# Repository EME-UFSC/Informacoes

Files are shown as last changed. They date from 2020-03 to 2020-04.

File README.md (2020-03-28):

<p align="center">
  <a href="https://eme-ufsc.github.io/Informacoes/">
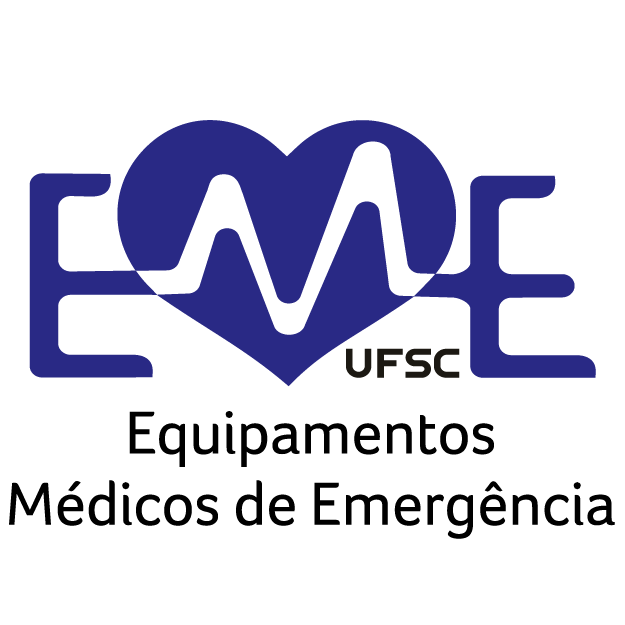
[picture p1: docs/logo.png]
Logo EME-UFSC
    
  </a>
</p>

## O que sao EMEs
Equipamentos médicos de emergencia (EMEs) sao equipamentos produzidos com o intuito de auxiliar no atendimento a emergencias médicas. Estes equipamentos nao sao certificados, porém passam por um controle no seu projeto e produçao para garantir que preencham requisitos minimos de ergonomia e higiene.

Atualmente o grupo EME-UFSC produz os seguintes equipamentos:
- Escudo facial
- Mascara de boca/nariz
- Avental
- Ventilador mecanico

## Quer ajudar ou precisa de ajuda?
Primeiramente precisamos saber onde voce precisa de ajuda ou como pode ajudar. Para isso, pedimos que preencha um dos formularios abaixo. **Demora menos de um minuto** e nos ajuda a gerenciar nossa demanda e capacidade de produçao. Em seguida [acesse nosso Slack](https://join.slack.com/t/eme-ufsc/shared_invite/zt-d20z4zog-~3Gnwx_5Q57T4ACO6nKYkg) e entre no canal mais adequado.

- #### Pode ajudar financeiramente? [**Clique aqui.**](docs/ajuda_financeira.md)

- #### Precisa de equipamento para sua Unidade de Saude? Preencha [este formulario](https://docs.google.com/forms/d/e/1FAIpQLSfDX15ljiZy6SYf0Oby2XscRVzy2pqgRojPx5fv6pEW_O75Uw/viewform).

- #### Possui maquinario para ajudar na produçao? Preencha [este formulario](https://forms.gle/Hm4whJZQ5EAF3oUG9).

- #### Possui algum dos [insumos aqui listados](docs/insumos.md) para doar ou vender? Preencha [este formulario](https://forms.gle/EKddxEwn4KSwLAXHA).

- #### Possui alguma duvida quanto ao projeto EME-UFSC? Preencha [este formulario](https://forms.gle/3jeLeoqR6PNNrrAi8).

- #### Aonde devo entregar os equipamentos? [Acesse aqui](docs/entrega.md).

## Outros links

- #### [Grupos de trabalho](docs/grupos_de_trabalho.md)
- #### [Projetos externos de EME](docs/projetos_externos_de_eme.md)
- #### [Arquivos para manufatura](docs/arquivos_de_manufatura.md)
- #### [Noticias](docs/noticias.md)
- #### [Resolução de fabricação e aquisição de dispositivos médicos em virtude da emergência de saúde pública](http://www.in.gov.br/en/web/dou/-/resolucao-rdc-n-356-de-23-de-marco-de-2020-249317437)

## Fotos da comunidade

- #### [Acervo local](docs/fotos/README.md)

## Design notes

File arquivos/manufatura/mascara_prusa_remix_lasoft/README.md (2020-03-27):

# Mascara modelo Prusa Remix Lasoft
Mascara de produção rapida e confortavel 

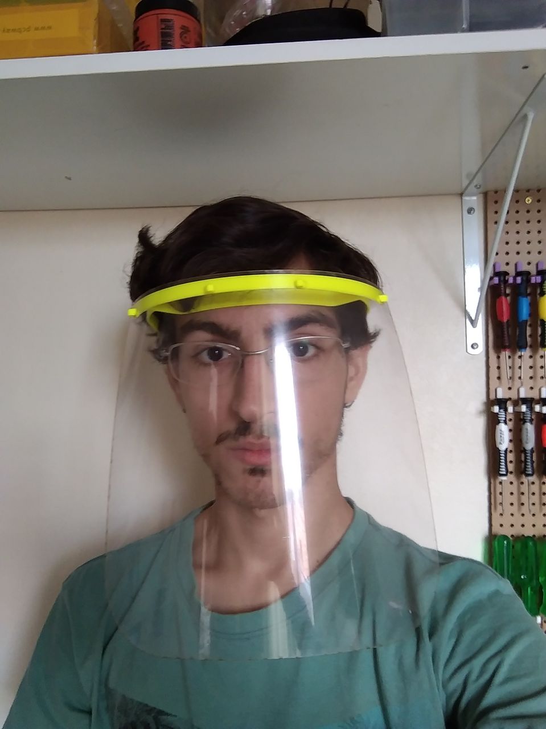
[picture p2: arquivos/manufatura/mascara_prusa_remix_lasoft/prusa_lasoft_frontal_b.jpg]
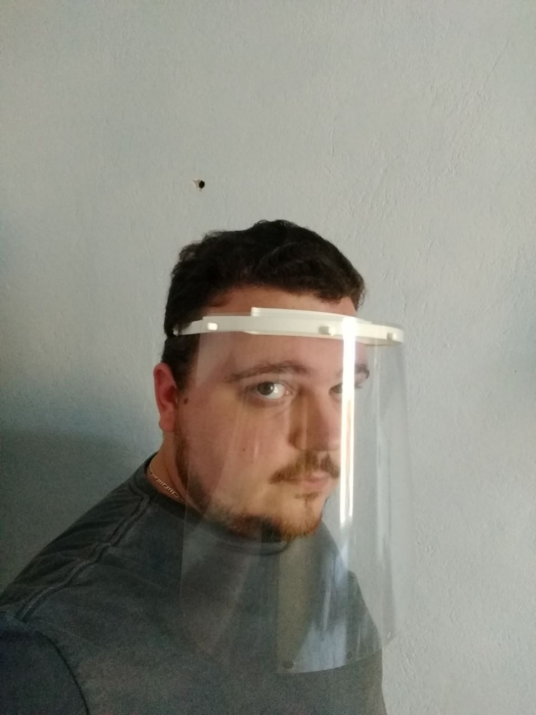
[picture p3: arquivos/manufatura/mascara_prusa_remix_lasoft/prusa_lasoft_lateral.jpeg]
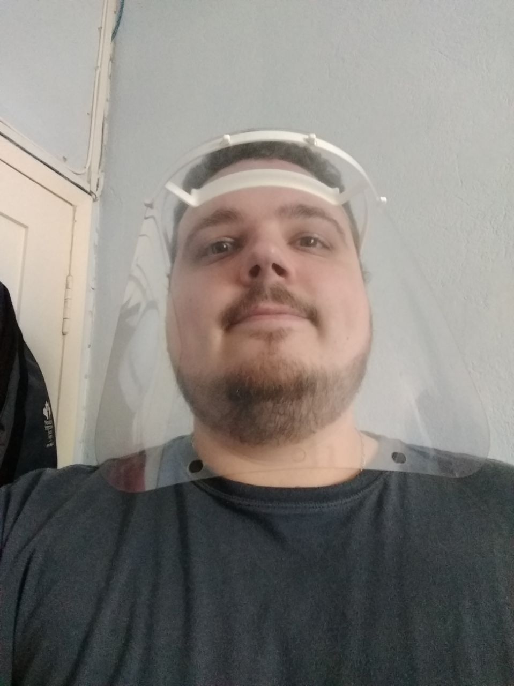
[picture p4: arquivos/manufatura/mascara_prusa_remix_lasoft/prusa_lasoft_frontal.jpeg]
  

## Arquivos
- [Suporte superior (.stl)](single-face-shield-lasoft-modified.stl)

## Vantagens
- Impressao rapida (1:30h)
- Pouco material (10g de filamento)

## Desvantagens
- Encaixe do acetato é quadrado

## BOM
- Suporte superior (impresso)
- Folha de acetato 24x24cm (0.5mm de espessura)
- Elastico

## Instruçoes para confecçao

- Imprimir os suportes
- Encaixar a folha de acetato
- Prender o elastico

## Configuraçao de impressao
- Numero de perimetros: 3;
- Percentual de infill: 20%;
- Altura de camada: 0.22mm;
- Velocidade planar: 60 mm/s;

## Limpeza
(?)

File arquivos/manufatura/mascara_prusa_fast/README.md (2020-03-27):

# Mascara-escudo modelo "Prusa FAST"
Modelo rapido desenvolvido pela empresa Prusa3D

## Arquivos
- [Suporte superior (.stl)](prusa_fast_superior.stl)
- [Suporte inferior (.stl)](prusa_fast_inferior.stl)
- [Desenho de corte (.dxf)](shield_final.dxf)

## Vantagens
- Ja validada por instituiçoes de saude
- Confortavel
- Firme
- Rapida
- Gasta pouco filamento

## Desvantagens
- N/A

## BOM
- Suporte superior (impresso)
- Suporte inferior (impresso)
- Folha de acetato 24x24cm (0.5mm de espessura)
- Elastico

## Instruçoes para confecçao

- Imprimir os suportes
- Encaixar a folha de acetato
- Prender o elastico

## Configuraçao de impressao
- Numero de perimetros: 3;
- Percentual de infill: 20%;
- Altura de camada: 0.22mm;
- Velocidade planar: 60 mm/s;

## Limpeza
(?)

## Referencia
https://blog.prusaprinters.org/from-design-to-mass-3d-printing-of-medical-shields-in-three-days/

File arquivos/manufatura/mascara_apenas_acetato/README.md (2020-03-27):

# Mascara modelo "Apenas Acetato"
Mascara de produção super rapida

## Arquivos
- [Instruçoes de montagem (.pdf)](Assembly_instruction.pdf)
- [Desenho de corte (.dxf)](https://eme-ufsc.github.io/Informacoes/arquivos/manufatura/mascara_apenas_acetato/shield_apenas_acetato.dxf)

## Vantagens
- Utiliza apenas acetato na estrutura, sem peças impressas
- Barata
- Rapida de produzir

## Desvantagens
- Ainda nao se conhece

## BOM
- Folha de acetato 22x30cm (0.5mm de espessura)
- Elastico

## Instruçoes para confecçao

- Cortar as peças na folha de acetato (aceita maquinas de corte a laser, corte a agua ou de laminas)
- Prender o elastico

## Limpeza
(?)

## Referencia
https://hackaday.io/project/170481-laser-cut-medical-shield

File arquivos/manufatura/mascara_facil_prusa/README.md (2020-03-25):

# Mascara-escudo modelo "Prusa RC2"
Modelo original desenvolvido pela empresa Prusa3D

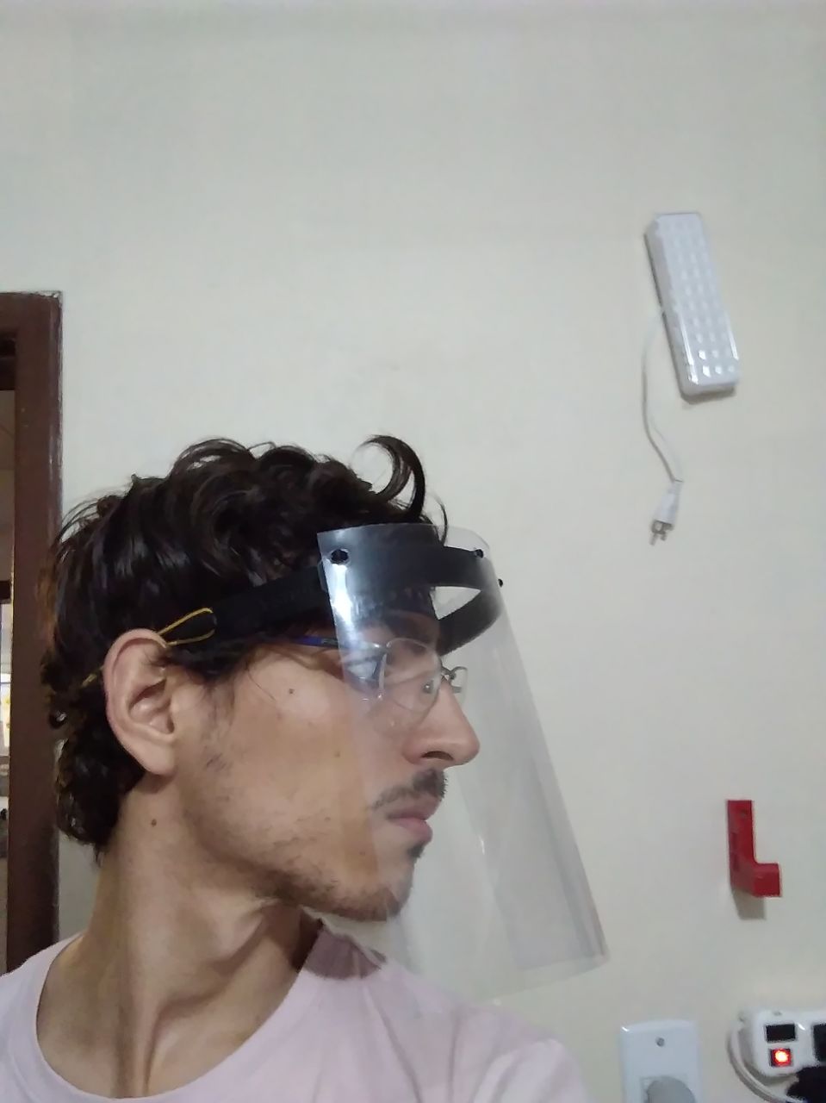
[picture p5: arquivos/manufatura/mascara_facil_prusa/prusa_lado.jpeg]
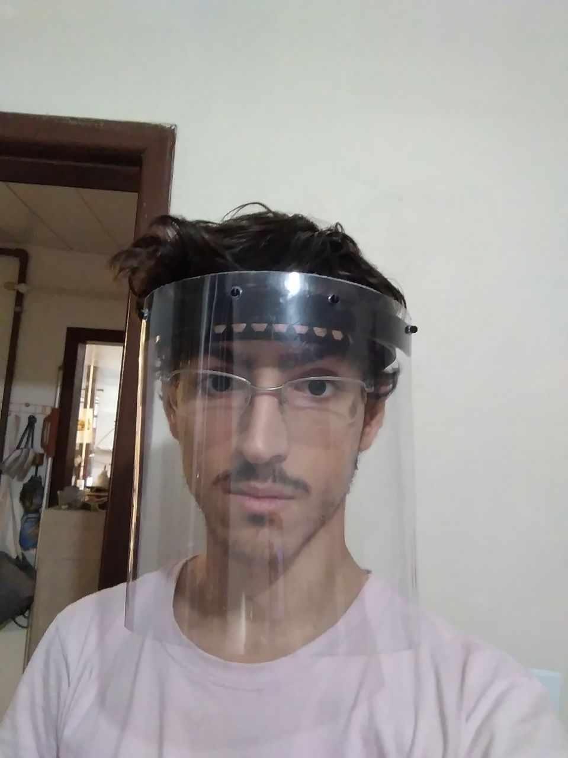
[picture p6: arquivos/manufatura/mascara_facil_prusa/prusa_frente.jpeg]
 

## Arquivos
- [Suporte superior (.stl)](covid19_headband_rc2.stl)
- [Suporte inferior (.stl)](bottom_reinforcement.stl)
- [Desenho de corte (.dxf)](shield_final.dxf)

## Vantagens
- Ja validada por instituiçoes de saude
- Confortavel
- Firme

## Desvantagens
- Impressao demorada (6h)
- Pouco material (40g de filamento)

## BOM
- Suporte superior (impresso)
- Suporte inferior (impresso)
- Folha de acetato 24x24cm (0.5mm de espessura)
- Elastico

## Instruçoes para confecçao

- Imprimir os suportes
- Encaixar a folha de acetato
- Prender o elastico

## Configuraçao de impressao
- Numero de perimetros: 3;
- Percentual de infill: 20%;
- Altura de camada: 0.22mm;
- Velocidade planar: 60 mm/s;

## Limpeza
(?)

## Referencia
https://blog.prusaprinters.org/from-design-to-mass-3d-printing-of-medical-shields-in-three-days/

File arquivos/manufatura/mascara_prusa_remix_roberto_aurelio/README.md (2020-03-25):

# Mascara modelo "Prusa" modificado por Roberto e Aurelio
Modelo original prusa

## Arquivos
- [Suporte superior (.stl)](prusa_remix_roberto_aurelio.STL)
- [Suporte inferior (.stl)](bottom_reinforcement.stl)
- [Desenho de corte (.pdf)](prusa_remix_roberto_aurelio_gabarito_furos.pdf)

## Vantagens
- Imprimi mais rapidamente que o modelo prusa original

## Desvantagens
- Impressao demorada (3h)

## BOM
- Suporte superior (impresso)
- Suporte inferior (impresso)
- Folha de acetato 24x24cm (0.5mm de espessura)
- Elastico

## Instruçoes para confecçao
- Imprimir os suportes
- Encaixar a folha de acetato
- Prender o elastico

## Configuraçao de impressao
- Numero de perimetros: 3;
- Percentual de infill: 20%;
- Altura de camada: 0.22mm;
- Velocidade planar: 60 mm/s;

## Limpeza
(?)

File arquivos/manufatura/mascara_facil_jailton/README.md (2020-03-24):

# Mascara modelo "Jailton"
Mascara de produção rapida

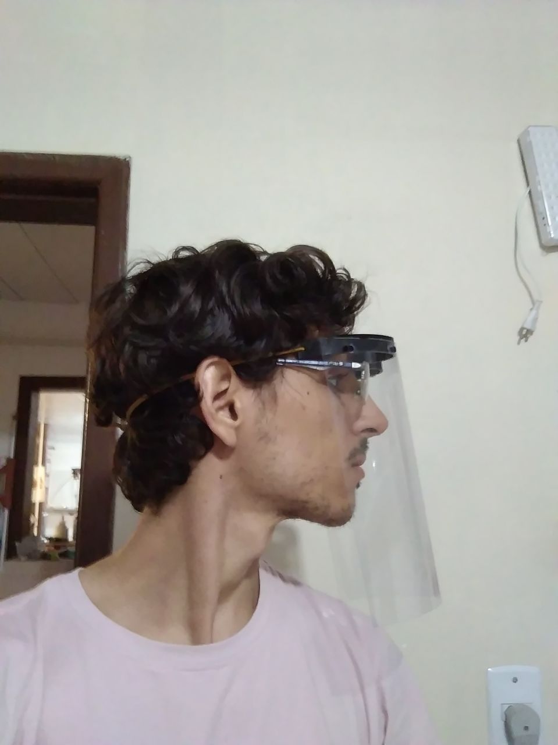
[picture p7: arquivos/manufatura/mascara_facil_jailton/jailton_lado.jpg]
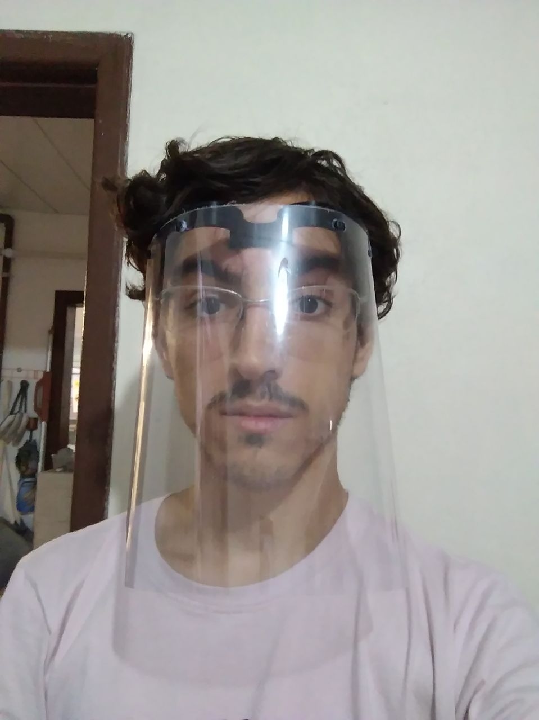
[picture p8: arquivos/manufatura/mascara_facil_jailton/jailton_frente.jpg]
 

## Arquivos
- [Suporte superior (.stl)](MASCARA_JAILTON.STL)
- [Gabarito para furaçao manual (.stl)](Gabarito_somente_Furos.stl)
- [Gabarito para corte e furaçao completo (.stl)](gabarito_completo.stl)
- [Desenho de corte (.dxf)](CORTE_ACETATO_MASCARA_JAILTON.DXF)
- [Desenho de corte (.pdf)](CORTE_ACETATO_MASCARA_JAILTON.PDF)

## Vantagens
- Impressao rapida (2h)
- Pouco material (10g de filamento)

## Desvantagens
- Pressão na testa mal distribuída

## BOM
- Suporte superior (impresso)
- Suporte inferior (impresso)
- Folha de acetato 24x24cm (0.5mm de espessura)
- Elastico

## Instruçoes para confecçao

- Imprimir os suportes
- Encaixar a folha de acetato
- Prender o elastico

## Configuraçao de impressao
- Numero de perimetros: 3;
- Percentual de infill: 20%;
- Altura de camada: 0.22mm;
- Velocidade planar: 60 mm/s;

## Limpeza
(?)

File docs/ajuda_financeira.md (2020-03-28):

# Ajuda financeira

O EME-UFSC nao pode receber doaçao financeira direta, porem existem pessoas na nossa regiao trabalhando na mesma causa que podem. 

Se deseja realizar uma doaçao financeira que sera revertida na compra de insumos para fabricaçao e gasolina para as entregas, entre em contato com Leonardo Machado pelo seguinte telefone:

Telefone para doacao de material

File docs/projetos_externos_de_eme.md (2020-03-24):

# Projetos externos de EMEs
  - [Ventilador open hardware (oxygen.protofy)](https://www.oxygen.protofy.xyz/)
  - [Mascara de mergulho como respirador (easy covid19)](https://www.isinnova.it/easy-covid19)
  - [Mascara simples com clip de papel](https://www.prusaprinters.org/prints/26318-simple-clip-for-face-mask-corona-virus-covid-19-pr)
  - [Mascara permanente impressa](https://www.cnn.com/2020/03/23/us/coronavirus-3d-printed-medical-supplies-trnd/index.html)
  - [Escudo facil da prusa (face shield)](https://www.prusaprinters.org/prints/25857-prusa-protective-face-shield-rc2/files)
  - [Escudo facil com corte a laser](https://hackaday.io/project/170481-laser-cut-medical-shield)
  - [Projeto respirador EME-UFSC](https://github.com/joaoantoniocardoso/colab_respirador)
  - [Projeto respirador LHC campinas](https://respiradorhacker.github.io/)
  - [Projeto respirador MIT](https://e-vent.mit.edu/)
  - [Modelo preditivo SEIR-Bayes do corona pelo brasil, estados e municipios](https://covid-simulator.3778.care/)

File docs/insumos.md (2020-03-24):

# Insumos

Para a produçao dos EMEs nossa equipe precisa de alguns insumos, entre eles:

- Folha de acetato (0.3mm)
- Filamento polimerico (PLA, ABS, PETG)
- Elastico
- Tecidos (SMS, TNT)

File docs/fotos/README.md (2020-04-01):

# Fotos da comunidade

### 01/04/2020 - Doação dos Bombeiros de PLA

### 28/03/2020 - Bombeiros de Florianópolis
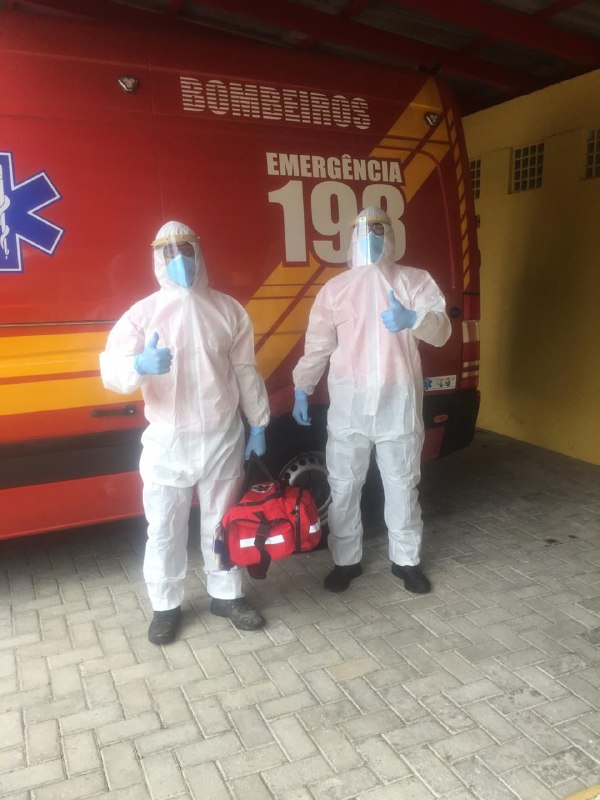
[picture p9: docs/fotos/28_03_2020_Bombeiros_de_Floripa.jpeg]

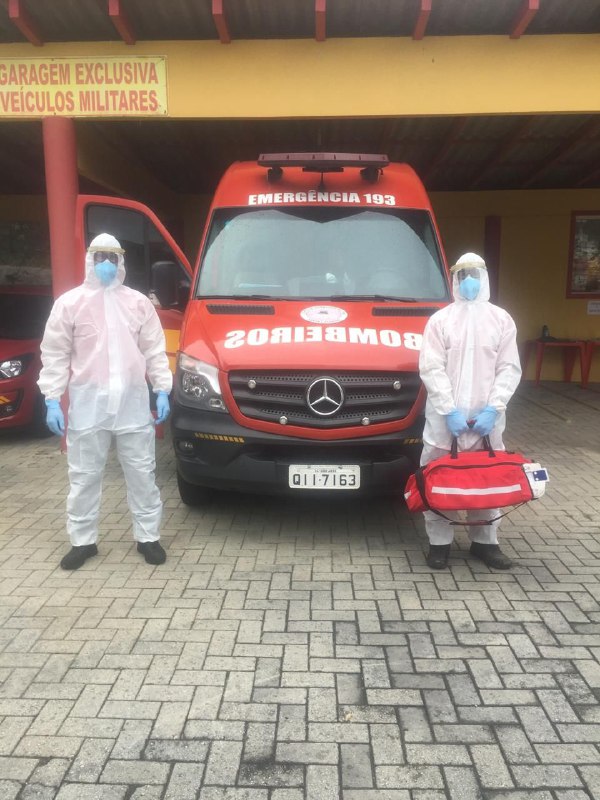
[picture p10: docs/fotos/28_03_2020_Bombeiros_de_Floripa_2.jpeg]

### 27/03/2020 - Doação de filamento para TreshDê Floripa 
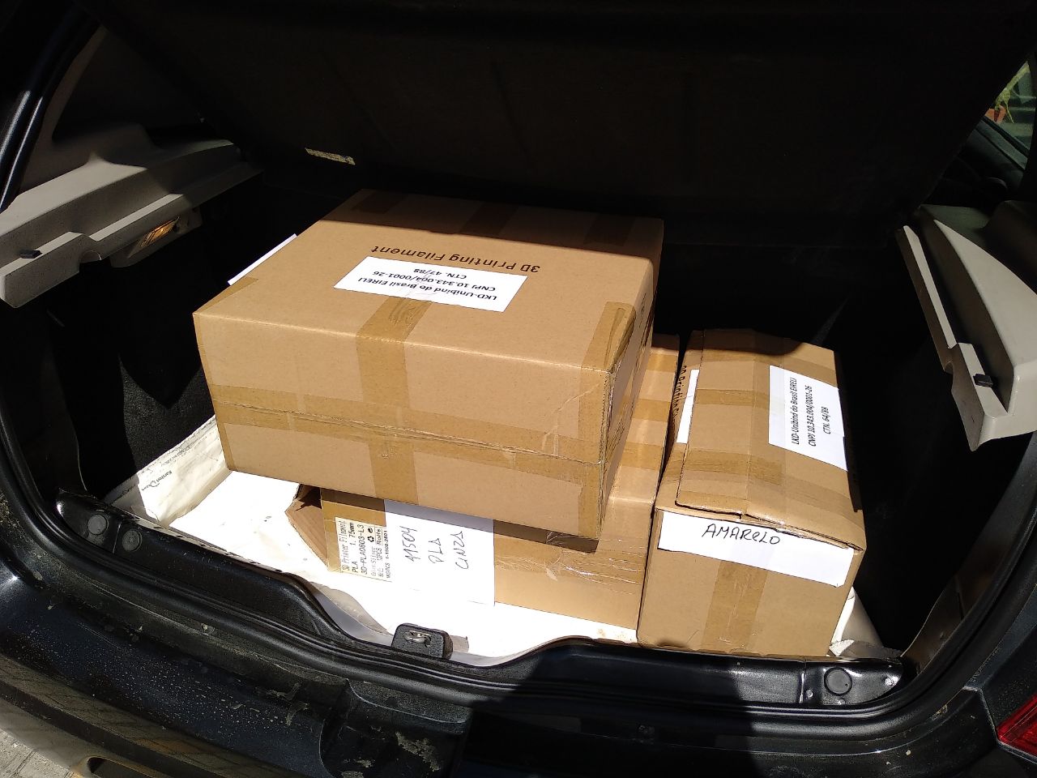
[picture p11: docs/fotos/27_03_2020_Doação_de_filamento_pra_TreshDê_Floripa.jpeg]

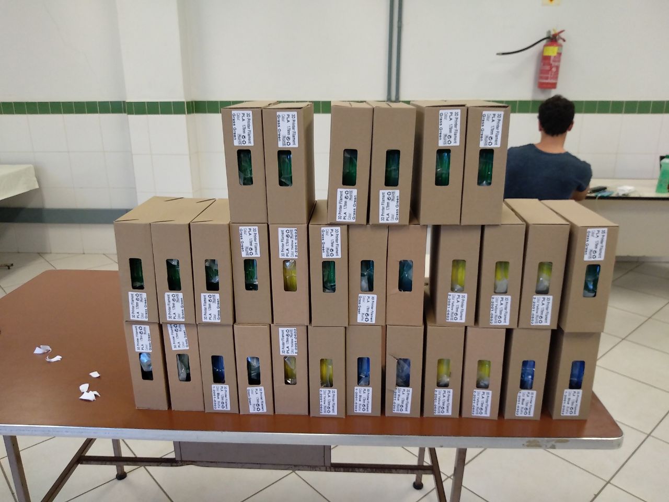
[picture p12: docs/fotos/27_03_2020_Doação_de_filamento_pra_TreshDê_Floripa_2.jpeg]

### 27/03/2020 - UPA de Biguaçu
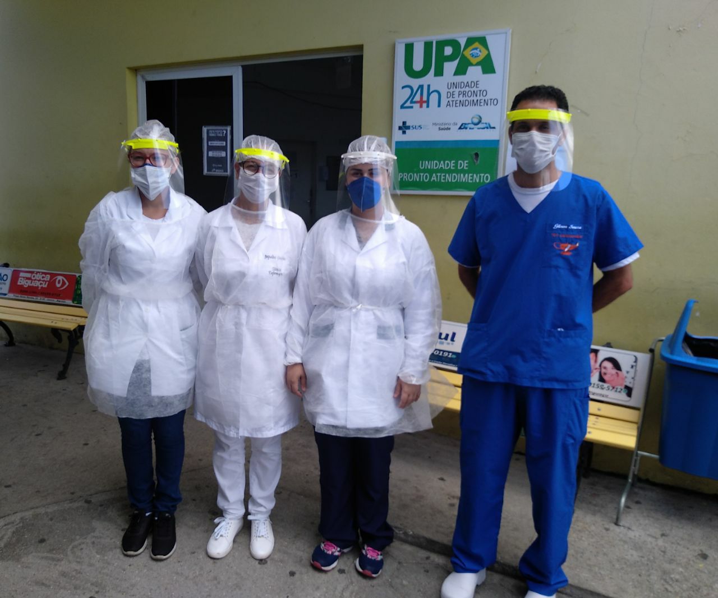
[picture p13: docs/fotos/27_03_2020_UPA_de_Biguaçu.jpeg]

### 25/03/2020 - Centro Odontológico de Biguaçu
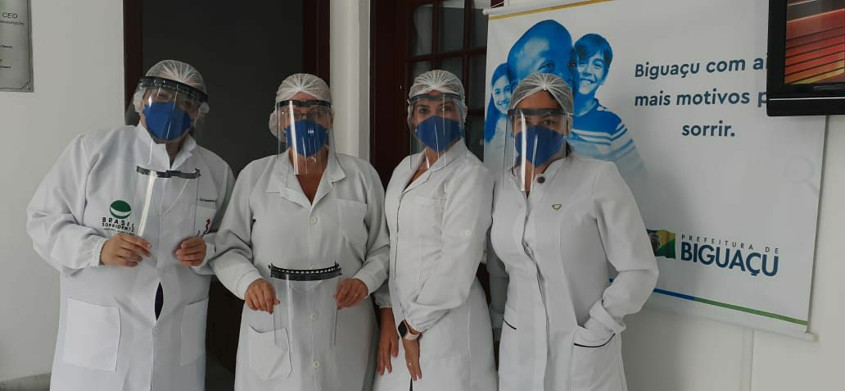
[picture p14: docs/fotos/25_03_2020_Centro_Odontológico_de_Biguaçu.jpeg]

### 25/03/2020 - PósDesign e PPGEP UFSC
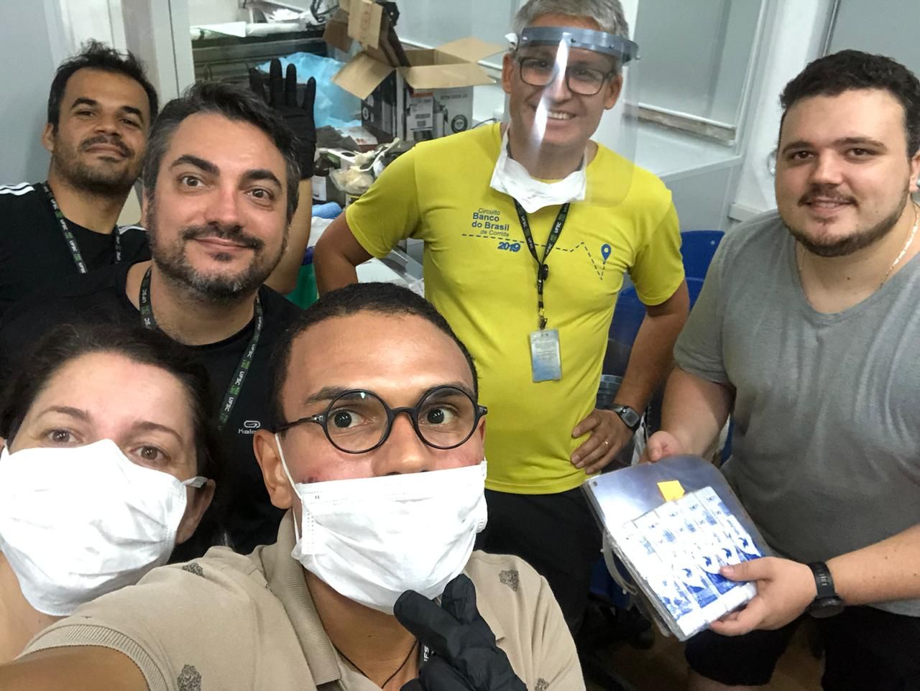
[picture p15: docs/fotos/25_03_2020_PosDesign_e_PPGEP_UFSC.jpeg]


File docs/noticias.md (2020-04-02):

# Noticias
  - [Médicos usam saco plástico no lugar de equipamento de proteção no Hospital Salgado Filho, Zona Norte do Rio](https://g1.globo.com/rj/rio-de-janeiro/noticia/2020/03/20/medicos-usam-saco-plastico-no-lugar-de-equipamento-de-protecao-no-hospital-salgado-filho-zona-norte-do-rio.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)
  - ['A worldwide hackathon': Hospitals turn to crowdsourcing and 3D printing amid equipment shortages](https://www.nbcnews.com/tech/innovation/worldwide-hackathon-hospitals-turn-crowdsourcing-3d-printing-amid-equipment-shortages-n1165026)
  - [As máscaras N95 podem ser esterilizadas e reutilizadas praticamente sem perda da eficiência da filtragem por 30 minutos em 70C](https://m.box.com/shared_item/https%3A%2F%2Fstanfordmedicine.box.com%2Fv%2Fcovid19-PPE-1-1)
  - [ABNT disponibiliza normas técnicas gratuitamente para ajudar a prevenir o contágio do COVID-19](
http://www.abnt.org.br/noticias/6786-abnt-disponibiliza-normas-tecnicas-gratuitamente-para-ajudar-a-prevenir-o-contagio-do-covid-19)

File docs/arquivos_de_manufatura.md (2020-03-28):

# Arquivos para manufatura

## Mascara do tipo "escudo" (*face shield*)
O unico modelo validado pelos agentes de saude atualmente é o "Modelo Prusa RC2". Caso nao tenha motivos especificos para produzir um dos outros, produza esse.

### Modelo principal
  - [Modelo Prusa Remix Lasoft](../arquivos/manufatura/mascara_prusa_remix_lasoft)
  
### Outros modelos
  - [Modelo Prusa FAST (RC3)](../arquivos/manufatura/mascara_prusa_fast)
  - [Modelo Roberto-Aurelio](../arquivos/manufatura/mascara_prusa_remix_roberto_aurelio)
  - [Modelo Jailton](../arquivos/manufatura/mascara_facil_jailton)
  - [Modelo Prusa RC2](../arquivos/manufatura/mascara_facil_prusa)
  - [Modelo Apenas Acetato](../arquivos/manufatura/mascara_apenas_acetato)
  
### Montagem
  - [Manual de montagem](manual_montagem.pdf)
  
### Folheto
Favor imprimir este folheto e colocar junto a mascara na entrega. Ele contem instruçoes quanto ao uso e higienizaçao.
  - [Folheto AR Brasil](etiqueta_ar_brasil.pdf)
  
### Procedimento Operacional Padronizado (POP)
  - [Utilização, colocação, retirada e limpeza do protetor de face (Face Shield)](POP_face_shield.pdf)
  
### Limpeza
  - [Desinfecção de mascaras faciais - (Prusa em ingles)](https://help.prusa3d.com/en/article/prusa-face-shield-disinfection_125457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)

### Nota:
Pela resolução da Anvisa, o recomendado é usar chapas de 0.5mm de acetato para as face shields.

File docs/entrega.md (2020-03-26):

# Aonde entregar

No momento estamos fazendo entregas com pedidos emergenciais diretos, iremos apontar um responsavel ou local logo.

## Outros locais

 - #### [Mapa de locais - e-enable Brasil](http://e-nablebrasil.org/wp/cadaimpressaoconta/)

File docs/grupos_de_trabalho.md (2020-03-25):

# Grupos de trabalho externos
  - [Trello do fab lab de joinville](https://trello.com/b/d1OyUROT/fab-lab-jlle-covid19)
  - [Grupo de consultoria OSS internacional (covid oss help)](https://covid-oss-help.org/)
  - [EME UFSC - grupo multidisciplinar da UFSC](https://eme.ufsc.br/)
    - [Equipamentos Médicos de Emergência UFSC - EME-UFSC](https://docs.google.com/forms/d/e/1FAIpQLSeCZE8CdgZPJN08dR_9Emt4Lmj818ivS3bxzDP5n7IXFxugCQ/viewform)
  - [Fórum para discussão sobre a criação de respiradores / ventiladores abertos (em espanhol)](https://foro.coronavirusmakers.org/)
 - Open Source COVID19 Medical Supplies ([Documento](https://docs.google.com/document/d/1-71FJTmI1Q1kjSDLP0EegMERjg_0kk_7UfaRE4r66Mg/preview)) ([Grupo no Facebook](https://www.facebook.com/groups/opensourcecovid19medicalsupplies//))
 - [Fazendo mascaras (Make masks - ingles)](https://www.makemasks2020.org/volunteer)

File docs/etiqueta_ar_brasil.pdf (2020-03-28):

## INICIATIVA CONTRA O COVID - 19

EPI NÃO DESCARTÁVEL,

### HIGIENIZAR ANTES DO USO

# FACE SHIELD

Máscaras de proteção facial feita de polímero transparente, que serve exclusivamente para criar uma barreira física transparente, ajudando a evitar que a saliva seja arremessada ao tossir, falar e/ou espirrar. Serve como um EPI, criando uma barreira mecânica que reforça a prevenção do contágio de doenças respiratórias.

Um produto que já é utilizado para proteção de olhos e boca na indústria geral como EPI, que agora serve como aliado na prevenção;

Não considerado um produto para a saúde.

Higienização
Antes e após o uso, os “visores de segurança” devem ser higienizados com água e detergente neutro. Passível de reutilização desde que higienizado.

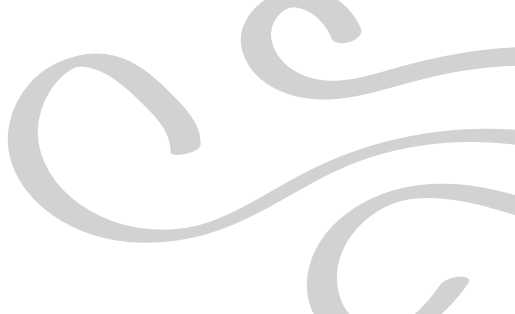
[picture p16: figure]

DISTRIBUIÇÃO GRATUITA

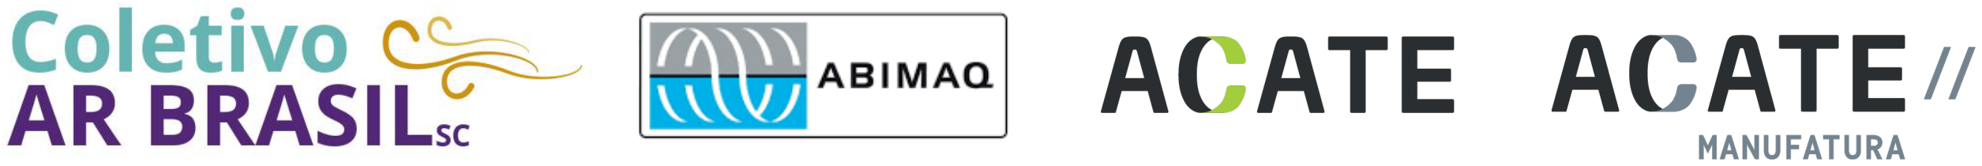
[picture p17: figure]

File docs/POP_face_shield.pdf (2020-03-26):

Hospital Universitário Prof. Polydoro Ernani de São Thiago da Universidade Federal de Santa Catarina | Procedimento Operacional Padronizado (POP) GERÊNCIA DE ATENÇÃO À SAÚDE Utilização, colocação, retirada e Limpeza do Protetor de Face (Face Shield) | POP nº 01/GAS/HU-UFSC Versão: 01 Próxima revisão:
Elaborado por: | Mariana Oliveira, Francine Lima Gelbcke, Claudia M. S. Oliveira, Graciele Trentin. | Data de criação: 24/03/2020
Revisado por: | | Data de revisão:
Aprovado por: | | Data de aprovação:

Local de guardo do documento:

Responsável pelo POP e pela utilização:

Objetivo: | Orientar a colocação, retirada e higienização adequada dos protetores faciais (Face Shield), produzidos para serem utilizados na pandemia de coronavírus - COVID-19
Setor: | | Agentes: enfermeiros, técnicos de enfermagem, médicos e demais equipes de saúde de instituições de saúde

### 1. Definição e Utilização

Os protetores faciais (com cobertura da face e das laterais do rosto) deverão ser utilizados sempre que houver risco de exposição do profissional às secreções corporais, ao sangue e excreções. São de uso, preferencialmente individual, utilizado em casos de procedimentos que produzam aerossol e/ou gotículas (Anvisa, 2020). O Protetor facial foi confeccionado com o material acetato. A utilização do protetor facial (face shield) não substitui o uso do óculos de proteção.

### 2. Colocação do Protetor Facial

- Realizar a lavagem das mãos com água e solução degermante ou assepsia com álcool gel 70% com a técnica adequada.
- Paramentar-se com avental.
- Colocar a máscara cirúrgica ou N95.
- Colocar óculos de proteção.
- Colocar protetor facial.
- Colocar touca descartável (deve cobrir o elástico do protetor facial).
- Colocar luvas.
- Toda a colocação de (Equipamentos de Proteção Individual - (EPI) seguir o passo a passo preconizado pela Anvisa.

### 3. Retirada do Protetor Facial

- Retire as luvas.
- Lave as mãos com água e sabão ou álcool à 70º.
- Retire o avental.
- Higienize as mãos com álcool a 70º
- Retire a touca.
- Retire o protetor facial tocando pelo elástico.
- Retirar o óculos
- Retire a máscara cirúrgica ou N95.
- Lave as mãos com solução degermante.

### 4. Limpeza do Protetor facial

- Realize a limpeza do protetor facial:
o desmontar a máscara, desconectar o visor da coroa/carneira, o retirar o elástico;
o lavar a coroa/carneira com água e sabão,
o enxaguar e secar,
o higienizar a máscara (acetato) com quaternário de amônia + biguanida ou outro padronizado na instituição;
o a limpeza do protetor facial deverá ocorrer ao final de cada uso.
o trocar o elástico sempre que houver sujidade visível.

### 5. Referências

Agência Nacional de Vigilância Sanitária. Orientações para serviços de saúde: medidas de prevenção e controle que devem ser adotadas durante a assistência aos casos suspeitos e confirmados de infecção pelo novo coronavírus (SARS-Cov-2). Norma técnica GVIMS/GGTES/
ANVISA | Nº | 04/2020 | (atualizado | em | 21/03/2020). | Disponível | em:
http://portal.anvisa.gov.br/documents/33852/271858/Nota+T%C3%A9cnica+n+04-
2020+GVIMS-GGTES-ANVISA/ab598660-3de4-4f14-8e6f-b9341c196b28. | Acessado | em:
24/03/2020.

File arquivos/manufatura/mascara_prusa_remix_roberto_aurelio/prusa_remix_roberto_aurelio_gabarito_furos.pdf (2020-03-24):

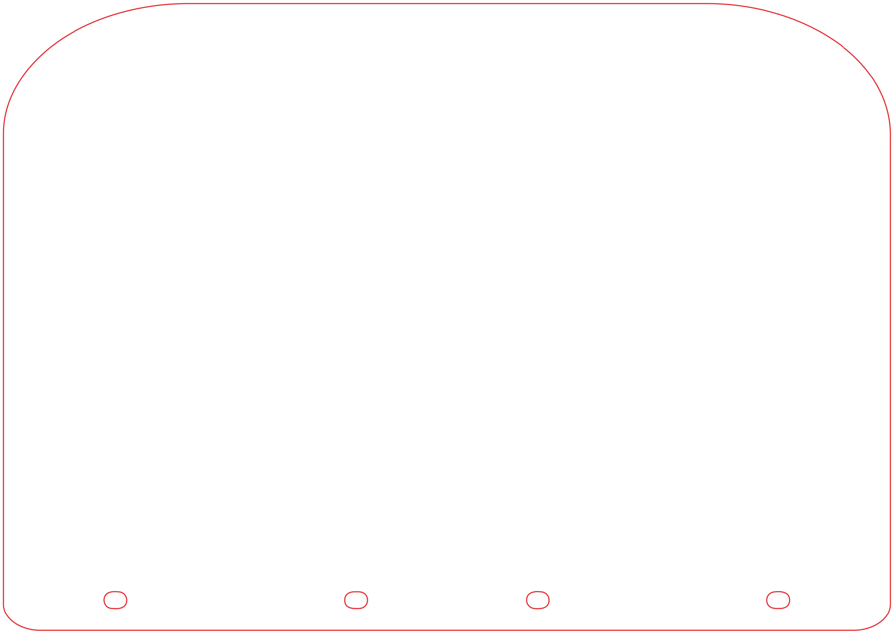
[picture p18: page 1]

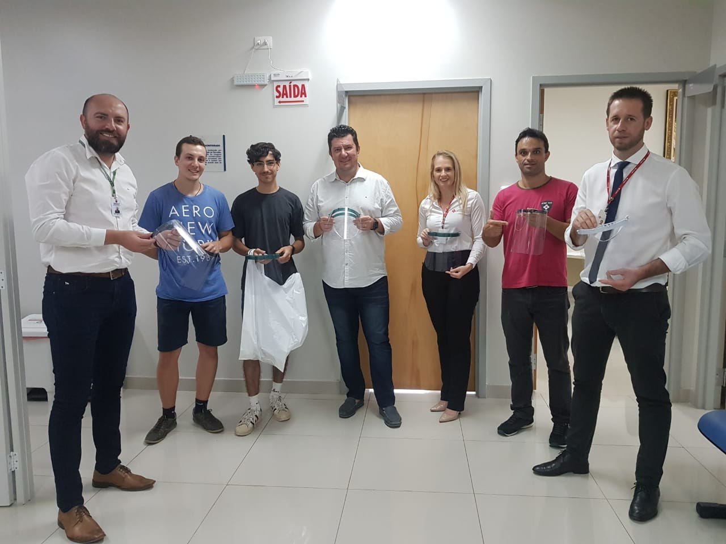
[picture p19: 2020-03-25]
docs/fotos/25_03_2020_Hospital_Regional_de_Biguaçu_Helmuth_Nass.jpeg

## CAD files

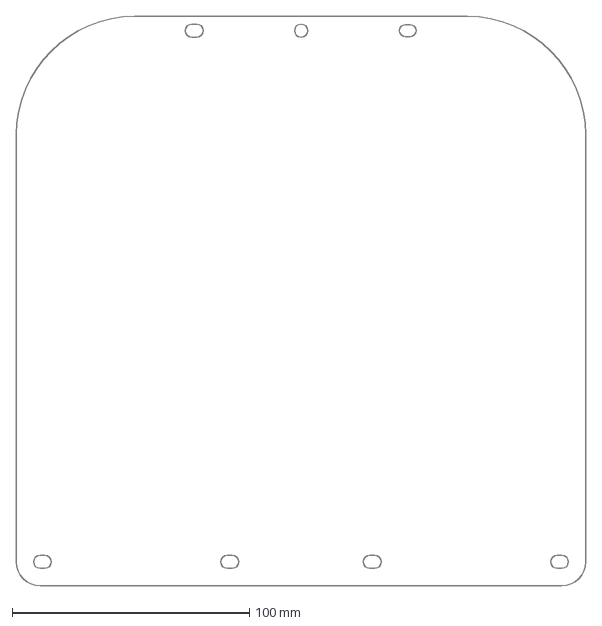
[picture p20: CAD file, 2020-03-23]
arquivos/manufatura/mascara_apenas_acetato/shield_apenas_acetato.dxf
240.0 x 240.0 mm

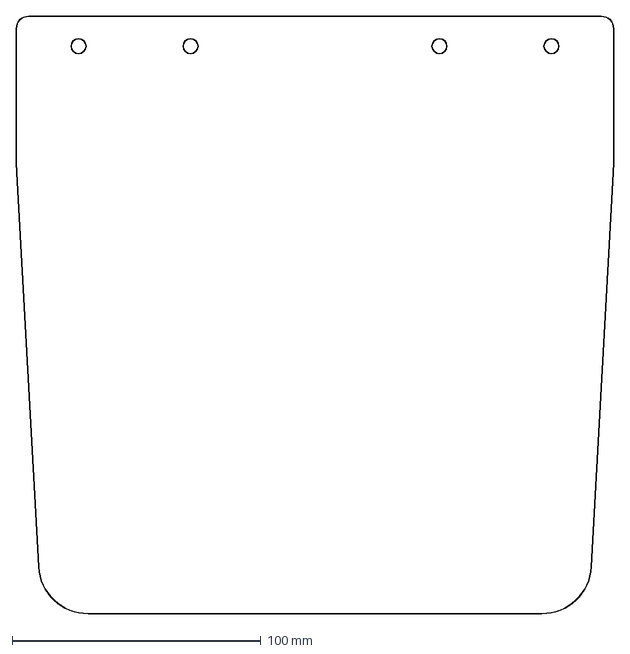
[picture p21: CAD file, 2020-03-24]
arquivos/manufatura/mascara_facil_jailton/CORTE_ACETATO_MASCARA_JAILTON.DXF
240.0 x 240.0 mm

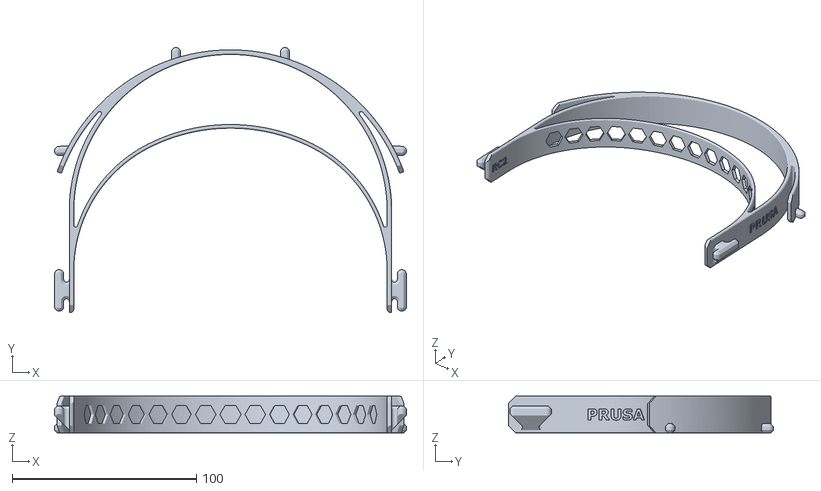
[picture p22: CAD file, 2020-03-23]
arquivos/manufatura/mascara_facil_prusa/covid19_headband_rc2.stl
191.0 x 143.8 x 20.0

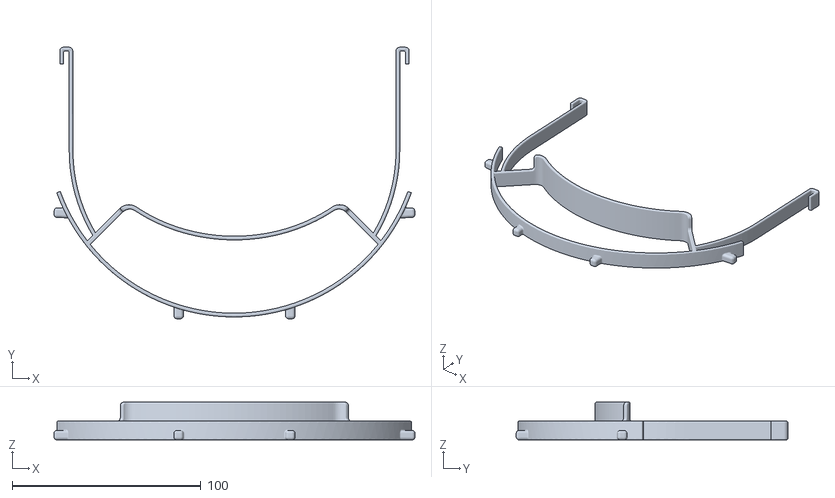
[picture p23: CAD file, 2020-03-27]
arquivos/manufatura/mascara_prusa_remix_lasoft/single-face-shield-lasoft-modified.stl
191.1 x 143.8 x 20.0

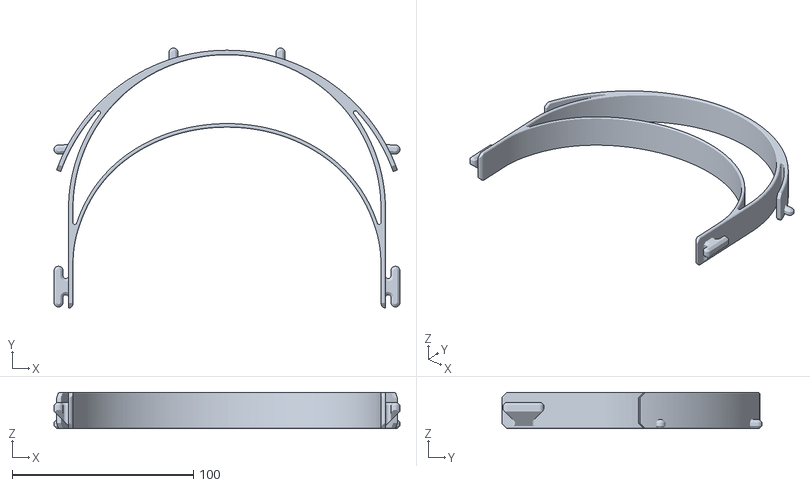
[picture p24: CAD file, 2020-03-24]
arquivos/manufatura/mascara_prusa_remix_roberto_aurelio/prusa_remix_roberto_aurelio.STL
191.0 x 143.6 x 20.0

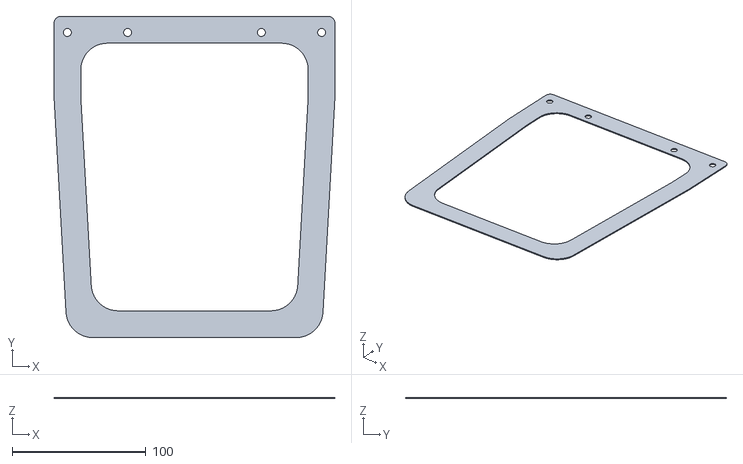
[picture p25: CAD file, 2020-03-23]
arquivos/manufatura/mascara_facil_jailton/gabarito_completo.stl
210.0 x 240.0 x 1.00

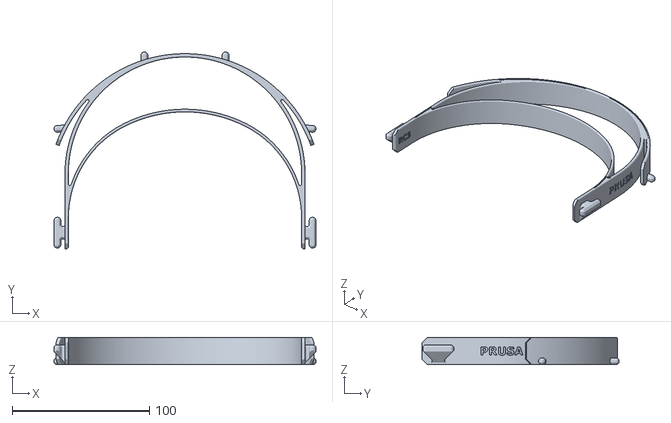
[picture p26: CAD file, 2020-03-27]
arquivos/manufatura/mascara_prusa_fast/prusa_fast_superior.stl
191.0 x 143.8 x 20.0

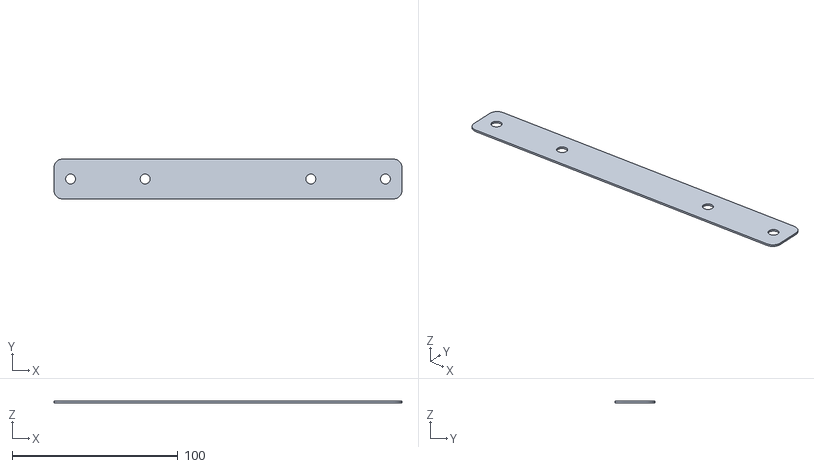
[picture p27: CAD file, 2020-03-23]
arquivos/manufatura/mascara_facil_jailton/Gabarito_somente_Furos.stl
210.0 x 24.0 x 1.00

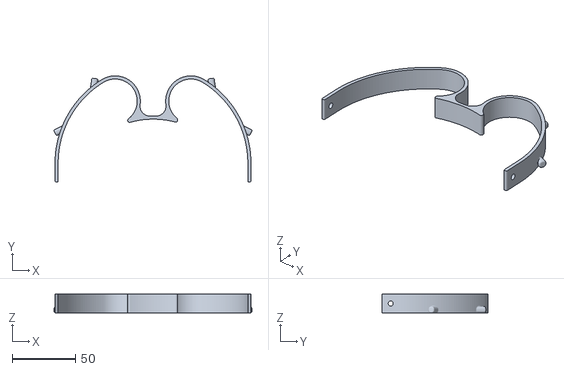
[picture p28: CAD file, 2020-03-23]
arquivos/manufatura/mascara_facil_jailton/MASCARA_JAILTON.STL
156.6 x 84.1 x 15.0

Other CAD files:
arquivos/manufatura/mascara_prusa_fast/shield_final.dxf

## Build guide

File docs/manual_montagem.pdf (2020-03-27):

## Equipamentos Médicos de Emergência UFSC EME - Máscaras tipo Face Shield

Aviso: O EME alerta sobre os atendimentos obrigatórios as resoluções da ANVISA, tais como RDC 40/2015, (http://portal.anvisa.gov.br/documents/33880/2568070/RDC_40_2015.pdf/ccfa7249-e8c0-469b-969a-b0844b09a8ce) 349/2020, (http://portal.anvisa.gov.br/noticias/-/asset_publisher/FXrpx9qY7FbU/content/simplificada-a-regularizacao-de-epis-e-outros-produtos/219201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) 356/2020, (http://portal.anvisa.gov.br/noticias/-/asset_publisher/FXrpx9qY7FbU/content/simplificada-a-regularizacao-de-epis-e-outros-produtos/219201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) além do atendimento as normas técnicas da ABNT. Mais informações sobre regras da ANVISA para coronavírus. (http://portal.anvisa.gov.br/coronavirus/regulamentos)

Este documento apresenta informações para confecção de máscaras do tipo Face Shield para proteção individual.

Importante:
- Os protetores faciais não podem manter saliências, extremidades afiadas, ou algum tipo de defeito que podem causar desconforto ou acidente ao usuário durante o uso.
- Deve ser facilitada a adequação ao usuário, a fim de que o protetor facial permaneça estável durante o tempo esperado de utilização.
- Caso não seja o consumidor final, informe-o das condições de fabricação.
- Haja como se você estivesse infectado! Utilize máscaras faciais e luvas novas para manipular as peças da máscara, e em caso de criação de estoque, após limpar as peças, sele as partes em um saco plástico em forma de kits para evitar contaminação.

https://eme.ufsc.br/

Modelo

Prusa RC2 | Prusa modificado por
Roberto e Aurelio | Jailton Jablonski

Arquivos e
informações

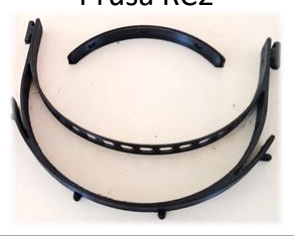
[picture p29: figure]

https://bit.ly/EME-PrusaRC2 (https://bit.ly/EME-PrusaRC2)

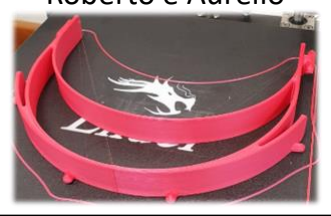
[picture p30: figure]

https://bit.ly/EME-PrusaRemix (https://bit.ly/EME-PrusaRemix)

https://bit.ly/EME-Jailton (https://bit.ly/EME-Jailton)

Vantagem

- Validação por
profissionais de
saúde;
- confortável e firme.

Modelo similar ao da
Prusa com pequenos
ajustes para imprimir
mais rapidamente.
- Impressão rápida
(2h);
- pouco material
(10g de filamento).

Desvantagem

- Impressão
demorada (6h);
- Mais material (40g
de filamento).
- Impressão
demorada (3h).
- Mais material
(pouco mais que
40g).

Pressão na testa mal
distribuída, podendo
causar desconforto
durante o uso.

Protetores faciais devem ser de uso exclusivo de cada profissional.

### 1. Limpeza:

Todas as partes devem ser limpas com água e sabão neutro e deixadas para secar naturalmente. Então as partes podem ser desinfetadas com álcool 70%, hipoclorito de sódio ou outro desinfetante recomendado pelo fabricante.

### 2. Esterilização:

Testes estão sendo feitos porém ainda não há informações sobre meios de esterilização destes materiais, assim não há recomendações precisas.

Não é recomendado a reutilização das máscaras, mas em casos onde haja reutilização é recomendada a limpeza da máscara entre o uso.

Todas as partes desmontáveis devem ser facilmente conectadas após a limpeza.

Limpeza e Esterilização

https://eme.ufsc.br/

## Equipamentos Médicos de Emergência UFSC EME - Máscaras tipo Face Shield

Manual

Ferramentas:
- Impressora 3D;
- Estilete, tesouras ou máquina de corte a laser.

Material:
- Filamento para Impressão (PLA, ABS, entre outros, sabemos que o PLA é atóxico, então damos preferência ao uso);
- Faixa elástica ou faixas ajustáveis ou autoajustáveis com o mínimo 10 milímetros de largura;
- Folhas de acetato ou outro material transparente com no mínimo 0.5 milímetros de espessura e 240 milímetros de largura e 240 milímetros de altura.

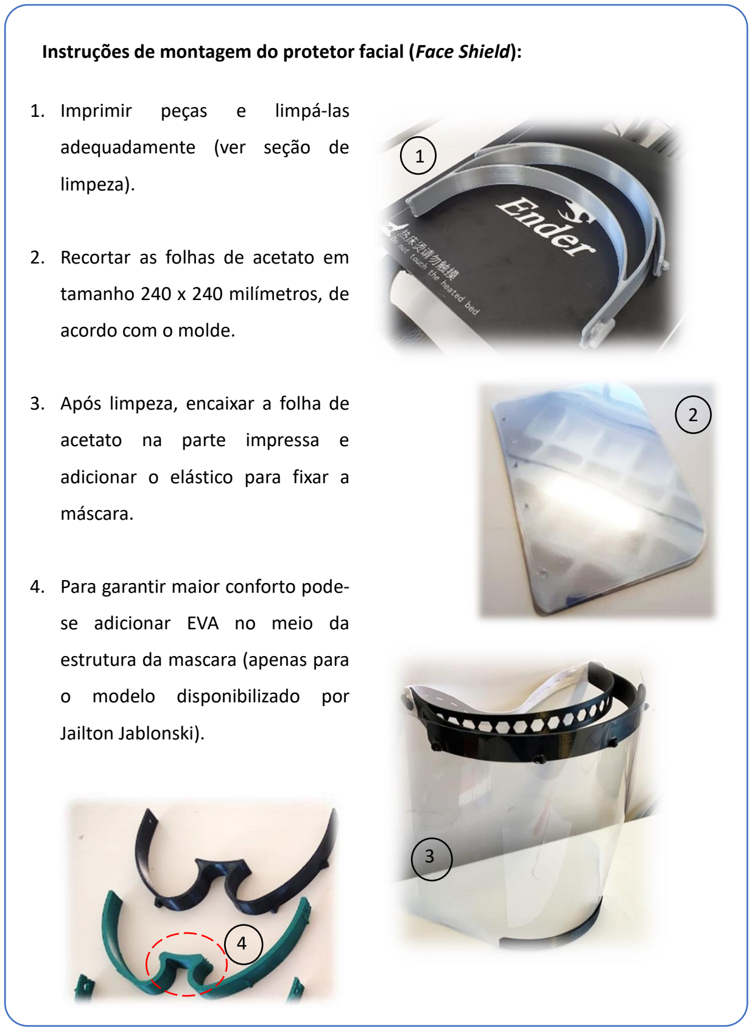
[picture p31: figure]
1. Imprimir; peças; limpá-las; adequadamente (ver seção de; limpeza).; 2. Recortar as folhas de acetato em; tamanho 240 x 240 milímetros, de; acordo com o molde.; 3. Após limpeza, encaixar a folha de; acetato na parte impressa e; adicionar o elástico para fixar a; máscara.; 4. Para garantir maior conforto pode-; se adicionar EVA no meio da; estrutura da mascara (apenas para; o modelo disponibilizado por; Jailton Jablonski).

Instruções de montagem do protetor facial (Face Shield):

https://eme.ufsc.br/

## Equipamentos Médicos de Emergência UFSC EME - Máscaras tipo Face Shield

Todos os modelos para impressão apresentados neste documento estão disponíveis em: https://eme-ufsc.github.io/Informacoes/docs/arquivos_de_manufatura.html

Arquivos e instruções de montagem do Modelo Prusa Protective Face Shield - RC2 são originalmente disponíveis em : https://www.prusaprinters.org/prints/25857-protective-face-shield-rc1 (https://www.prusaprinters.org/prints/25857-protective-face-shield-rc1) https://manual.prusa3d.com/Guide/How+to+assemble+the+Prusa+Face+Shield+-+RC1-RC2/1527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 (https://manual.prusa3d.com/Guide/How+to+assemble+the+Prusa+Face+Shield+-+RC1-RC2/1527)

Alerta feito pela Prusa: O vírus pode viver no plástico de 48 à 90 horas e plásticos não são facilmente esterilizáveis após o uso. Então é recomendado apenas um uso, até encontrarmos um modo comprovado de esterilização das partes impressas. (https://blog.prusaprinters.org/from-design-to-mass-3d-printing-of-medical-shields-inthree-days/) (https://blog.prusaprinters.org/from-design-to-mass-3d-printing-of-medical-shields-in-three-days/)

Este documento só se tornou possível graças a colaboração de professores, pesquisadores, profissionais da saúde, alunos e voluntários. Agradecemos à todos os envolvidos!

Quaisquer dúvidas na impressão do modelo disponibilizado por Jailton Jablonski entre em contato: jailtonjairjablonski@gmail.com

Para outras informações: https://github.com/EME-UFSC/Informacoes

https://eme.ufsc.br/

## Equipamentos Médicos de Emergência UFSC EME - Máscaras tipo Face Shield

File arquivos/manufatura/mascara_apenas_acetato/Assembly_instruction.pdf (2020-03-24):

# Medical shield

## Assembly instruction

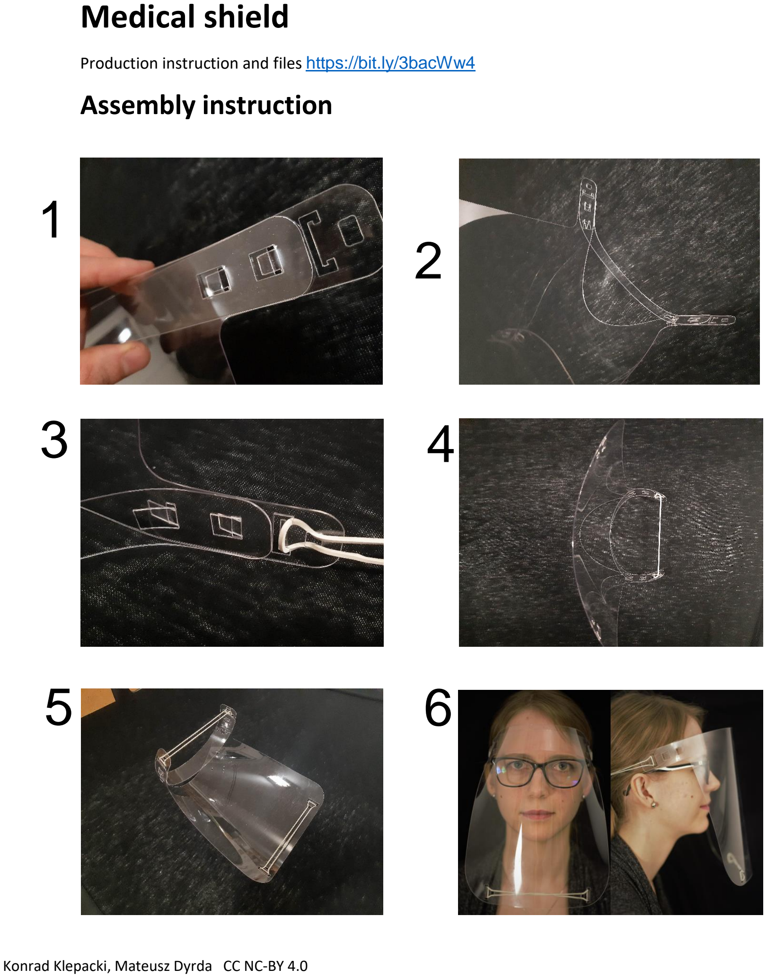
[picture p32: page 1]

Production instruction and files https://bit.ly/3bacWw4

1
2
3 | 4
5 | 6

Konrad Klepacki, Mateusz Dyrda CC NC-BY 4.0

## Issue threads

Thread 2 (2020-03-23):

Adicionar README relacionado aos arquivos de manufatura

patrickelectric, 2020-03-23:
Cada pasta de projeto deve ter um README que informa BOM e tbm as configurações da maquina de operação ou de impressão para impressoras 3D.

patrickelectric, 2020-03-23:
para as face shields, from leo:
> 3 perímetros 17% infill. O infill ta ali só pra segurar a casca, porque é quase maciço.
Camada 0.22 55mm/s,
> eu acho configs superestimadas, porque depende muito de altura de camada, velocidade, diametro do bico e os caralho. Por mim só dizer 3 perimetros infill 20% camada 0.22mm velocidade 60mm/s resolve e padroniza

patrickelectric, 2020-03-23:
>tem gente fazendo com 0.3mm de camada, alguns conseguem, mas a propabilidade de o pessoal fazer algo quebradiço é grande
minha extrusora se peida toda pra fazer 0.3mm nos 40mm/s ou mais rapido

rafaellehmkuhl, 2020-03-23:
Iniciado em #3

Closed 2020-03-23.

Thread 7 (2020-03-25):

Colocar disclaimer sobre vaquinhas online

rafaellehmkuhl, 2020-03-25:
Colocar este disclaimer em algum lugar:

Por questões legais, **ainda não estamos autorizados a receber doações em dinheiro** (nem possuímos "vaquinhas online"), porém você pode nos ajudar na compra dos insumos. Para isso, entre em contato com a gente através **deste link**.

O formulario ainda nao existe e ainda nao temos um lugar na pagina que de pra colocar isso sem atrapalhar as outras informaçoes.

Uma ideia é colocar um link assim: "**Pode ajudar financeiramente? Clique aqui.**". Este link redirecionaria para o texto anterior.

Closed 2020-03-25.

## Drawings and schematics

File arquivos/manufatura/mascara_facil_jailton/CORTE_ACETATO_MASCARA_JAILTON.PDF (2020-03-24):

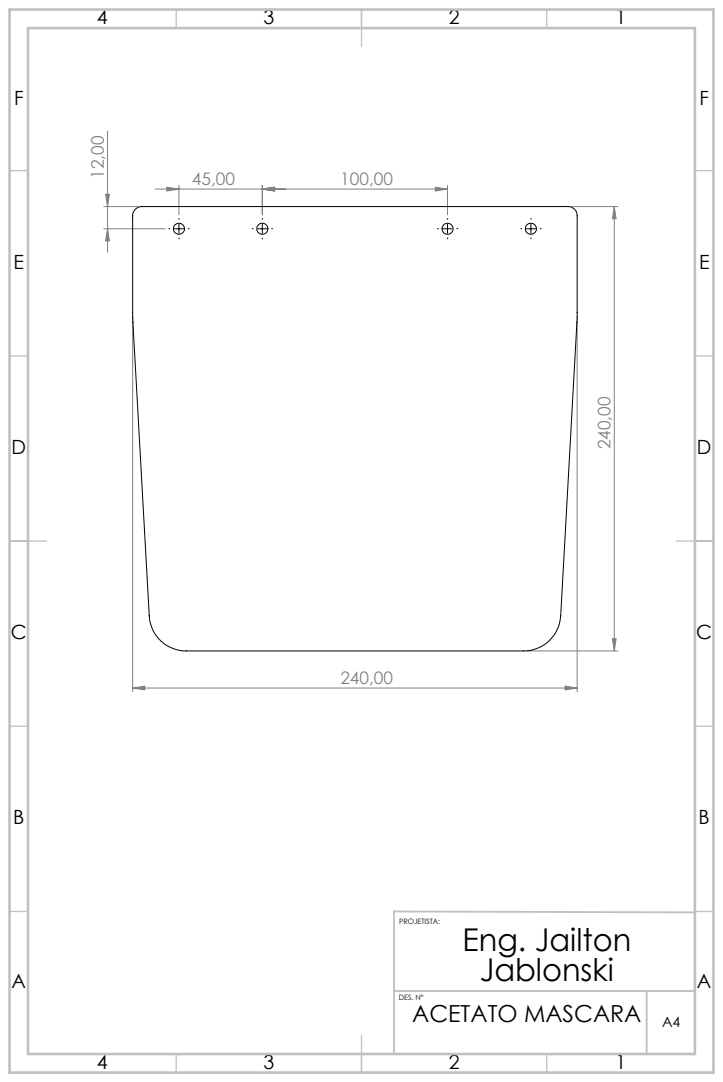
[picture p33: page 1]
DES. Nº; ACETATO MASCARA; Eng. Jailton

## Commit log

2020-03-23 Movendo projetos para a pasta arquivos
    [CORTE_ACETATO_MASCARA_JAILTON.DXF, MASCARA_JAILTON.STL, bottom_reinforcement.stl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]
2020-03-23 Move arquivos de manufatura para pasta propria
    [CORTE_ACETATO_MASCARA_JAILTON.DXF, MASCARA_JAILTON.STL, bottom_reinforcement.stl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]
2020-03-23 Criados READMEs individuais para cada equipamento
2020-03-24 Muda formulario de duvidas
2020-03-24 Adiciona arquivos da mascara "apenas acetato"
    [medical_shield_0_5mm.dxf]
2020-03-24 Adiciona referencias e arquivos nos manuais de manufatura
    [Gabarito_somente_Furos.stl]
2020-03-24 Atualiza os arquivos de corte da mascara modelo "Jailton"
    [CORTE_ACETATO_MASCARA_JAILTON.DXF]
2020-03-25 Adiciona arquivo de suporte inferior
    [bottom_reinforcement.stl]
2020-03-25 Modifica nomes e reorganiza
    Modifica o nome dos modelos de face shield e reorganiza os mesmos, deixando claro qual o modelo principal a ser fabricado.
2020-03-25 Referencia imagens relativamente
    Muda imagens para referencias relativas (não absolutas)
2020-03-25 Modifica tamanho das imagens
    Modifica tamanho das imagens para nao atrapalharem a visualizaçao das outras informaçoes
2020-03-25 Adiciona arquivo de disclaimer
2020-03-25 Adiciona imagem com numero para doaçao
2020-03-25 Adiciona arquivo de logo
2020-03-25 fotos: Renomeado para o nome correto
2020-03-27 Corrigido aquivo de corte
    [medical_shield_0_5mm.dxf.dxf]
2020-03-27 Atualiza corretamente o arquivo
    [medical_shield_0_5mm.dxf]
2020-03-27 Atualiza referencia para o .zip
    .dxf estava sendo corrompido
2020-03-27 Adiciona xdf para mascara acetato
    [shield_apenas_acetato.dxf]
2020-03-27 adiciona zip para acetato
2020-03-27 Adiciona manual de montagem
2020-03-27 Adiciona link para manual de montagem
2020-03-27 Adiciona novo manual de montagem
2020-03-27 Atualiza link para manual de montagem
2020-03-27 Adiciona arquivos de manufatura
    [prusa_fast_inferior.stl, prusa_fast_superior.stl, shield_final.dxf]
2020-03-28 Atualiza telefone para doaçao
2020-03-28 Adiciona novo telefone para doaçao
2020-03-28 Adiciona PDF para impressao
